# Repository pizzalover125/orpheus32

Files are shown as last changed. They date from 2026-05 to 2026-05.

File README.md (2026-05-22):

# orpheus32



An ESP32 devboard made for Hack Club. A rival to the famous Orpheus Pico. 

### features
- 23 GPIO
- Integrated WiFi + Bluetooth
- 2x UART
- 2x DAC (8-bit)
- SPI, I2C, I2S support
- User-addressable NeoPixel

### schematic + PCB




### KiCAD Render




### BOM
- PCB: $40.30 (incl. JLCPCB PCB, Assembly, Shipping, Customs, Taxes)
- Detailed BOM located in BOM.csv

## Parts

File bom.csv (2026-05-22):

Designator | Footprint | Quantity | Value | LCSC Part #
C2, C3, C4, C5, C6 | 0603 | 5 | 100nf
C7 | 0603 | 1 | 22uf
D1 | D_SOD-123 | 1 | B5819W
D2, D3 | 0603 | 2 | LED
D4 | LED_SK6812MINI_PLCC4_3.5x3.5mm_P1.75mm | 1 | SK6812MINI
J1 | USB_C_Receptacle_HRO_TYPE-C-31-M-12 | 1 | USB_C_Receptacle_USB2.0_16P
J2, J3 | PinHeader_1x15_P2.54mm_Vertical | 2 | Conn_01x15_Pin
Q1, Q2 | SOT-23 | 2 | SS8050
R1, R2 | 0603 | 2 | 5.1k
R3 | 0603 | 1 | 1K
R4, R5, R6 | 0603 | 3 | 10K
R7 | 0603 | 1 | 220R
SW1, SW2 | SW_Push_SPST_NO_Alps_SKRK | 2 | SW_Push
U1 | ESP32-WROOM-32 | 1 | ESP32-WROOM-32
U2 | SOIC-16_3.9x9.9mm_P1.27mm | 1 | CH340C
U3 | SOT-223-3_TabPin2 | 1 | AMS1117-3.3

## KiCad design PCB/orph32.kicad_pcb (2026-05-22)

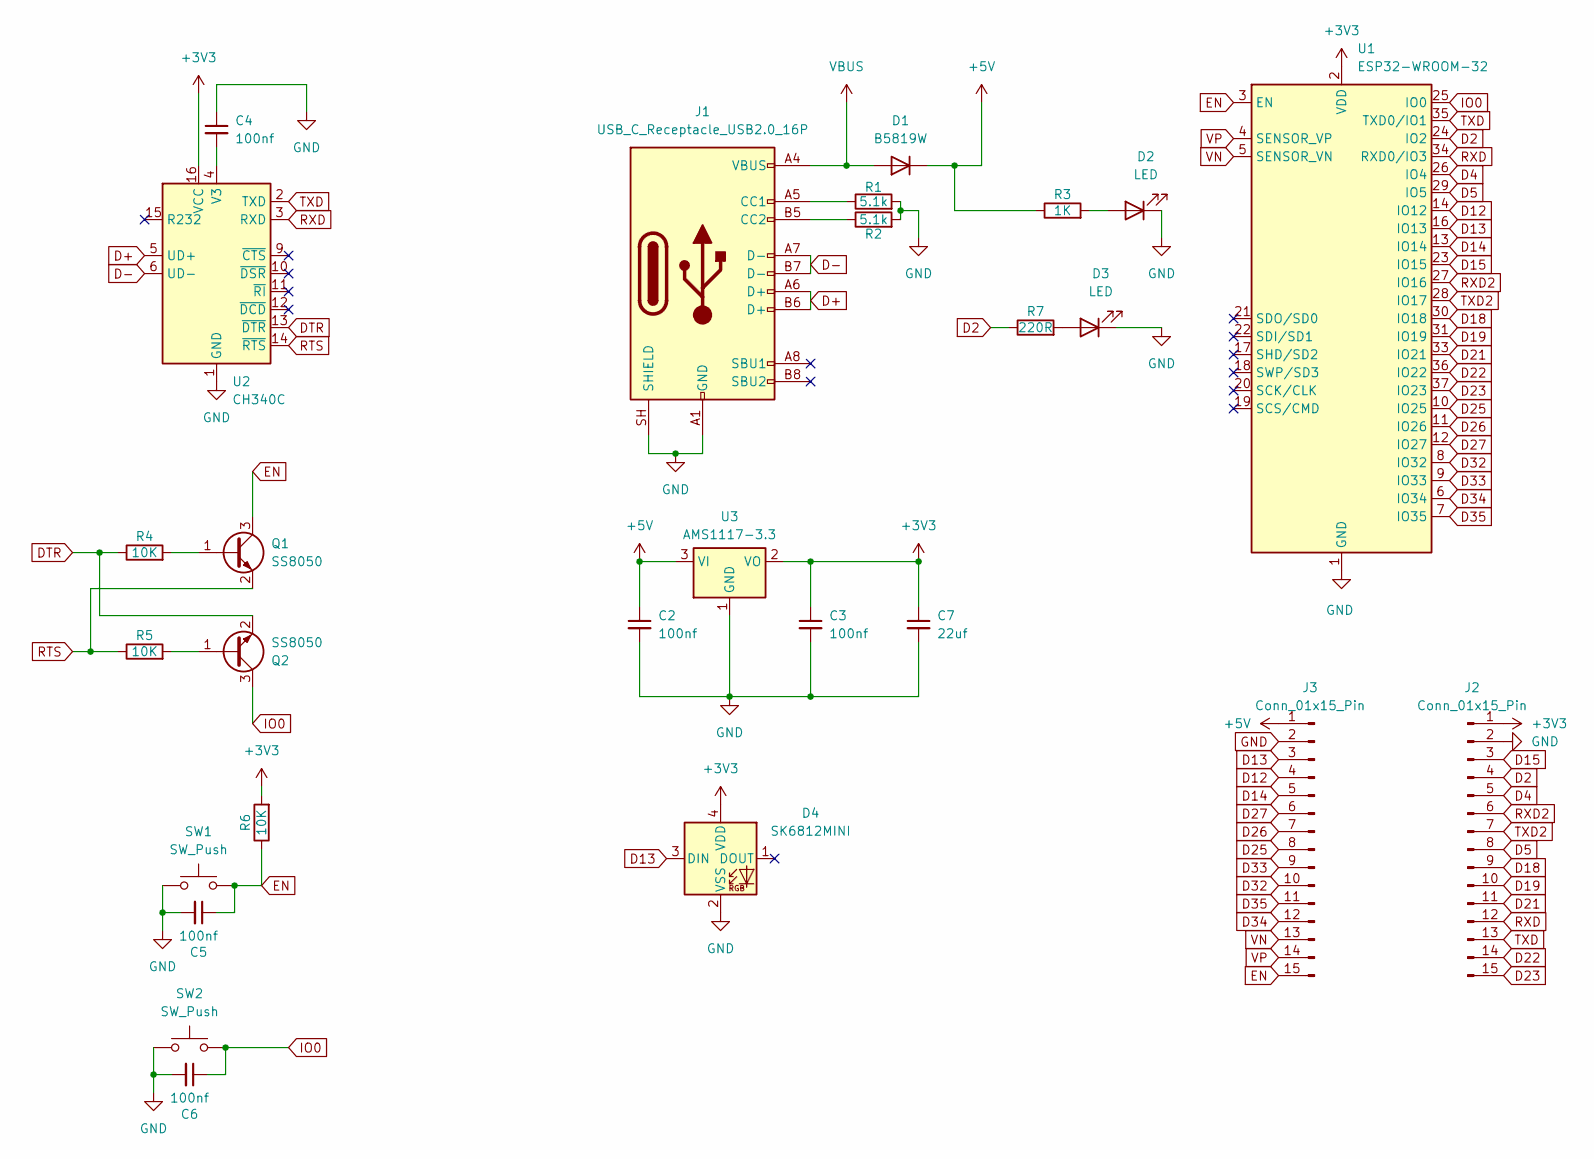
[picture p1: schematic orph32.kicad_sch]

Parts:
C2, C3, C4, C5, C6: 100nf; C_0603_1608Metric
C7: 22uf; C_0603_1608Metric
D1: B5819W; D_SOD-123
D2, D3: LED; LED_0603_1608Metric
D4: SK6812MINI; LED_SK6812MINI_PLCC4_3.5x3.5mm_P1.75mm
J1: USB_C_Receptacle_USB2.0_16P; USB_C_Receptacle_HRO_TYPE-C-31-M-12
J2, J3: Conn_01x15_Pin; PinHeader_1x15_P2.54mm_Vertical
Q1, Q2: SS8050; SOT-23
R1, R2: 5.1k; R_0603_1608Metric
R3: 1K; R_0603_1608Metric
R4, R5, R6: 10K; R_0603_1608Metric
R7: 220R; R_0603_1608Metric
SW1, SW2: SW_Push; SW_Push_SPST_NO_Alps_SKRK
U1: ESP32-WROOM-32
U2: CH340C; SOIC-16_3.9x9.9mm_P1.27mm
U3: AMS1117-3.3; SOT-223-3_TabPin2

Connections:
+3V3: C3.1, C7.1, D4.4 (VDD), J2.1, R6.2, U1.2 (VDD), U2.16 (VCC), U3.2 (VO)
+5V: C2.1, D1.1 (K), J3.1, R3.1, U3.3 (VI)
D2: J2.4, R7.1, U1.24 (IO2)
D4: J2.5, U1.26 (IO4)
D5: J2.8, U1.29 (IO5)
D12: J3.4, U1.14 (IO12)
D13: D4.3 (DIN), J3.3, U1.16 (IO13)
D14: J3.5, U1.13 (IO14)
D15: J2.3, U1.23 (IO15)
D18: J2.9, U1.30 (IO18)
D19: J2.10, U1.31 (IO19)
D21: J2.11, U1.33 (IO21)
D22: J2.14, U1.36 (IO22)
D23: J2.15, U1.37 (IO23)
D25: J3.8, U1.10 (IO25)
D26: J3.7, U1.11 (IO26)
D27: J3.6, U1.12 (IO27)
D32: J3.10, U1.8 (IO32)
D33: J3.9, U1.9 (IO33)
D34: J3.12, U1.6 (IO34)
D35: J3.11, U1.7 (IO35)
D+: J1.A6 (D+), J1.B6 (D+), U2.5 (UD+)
D-: J1.A7 (D-), J1.B7 (D-), U2.6 (UD-)
DTR: Q2.2 (E), R4.1, U2.13 (~DTR)
EN: C5.1, J3.15, Q1.3 (C), R6.1, SW1.2, U1.3 (EN)
GND: C2.2, C3.2, C4.1, C5.2, C6.2, C7.2, D2.1 (K), D3.1 (K), D4.2 (VSS), J1.A1 (GND), J1.A12 (GND), J1.B1 (GND), J1.B12 (GND), J1.SH (SHIELD), J2.2, J3.2, R1.2, R2.2, SW1.1, SW2.1, U1.1 (GND), U1.15 (GND), U1.38 (GND), U1.39 (GND), U2.1 (GND), U3.1 (GND)
IO0: C6.1, Q2.3 (C), SW2.2, U1.25 (IO0)
unnamed: D2.2 (A), R3.2
unnamed: D3.2 (A), R7.2
unnamed: J1.A5 (CC1), R1.1
unnamed: J1.B5 (CC2), R2.1
unnamed: Q1.1 (B), R4.2
unnamed: Q2.1 (B), R5.2
unnamed: C4.2, U2.4 (V3)
RTS: Q1.2 (E), R5.1, U2.14 (~RTS)
RXD: J2.12, U1.34 (RXD0/IO3), U2.3 (RXD)
RXD2: J2.6, U1.27 (IO16)
TXD: J2.13, U1.35 (TXD0/IO1), U2.2 (TXD)
TXD2: J2.7, U1.28 (IO17)
VBUS: D1.2 (A), J1.A4 (VBUS), J1.A9 (VBUS), J1.B4 (VBUS), J1.B9 (VBUS)
VN: J3.13, U1.5 (SENSOR_VN)
VP: J3.14, U1.4 (SENSOR_VP)

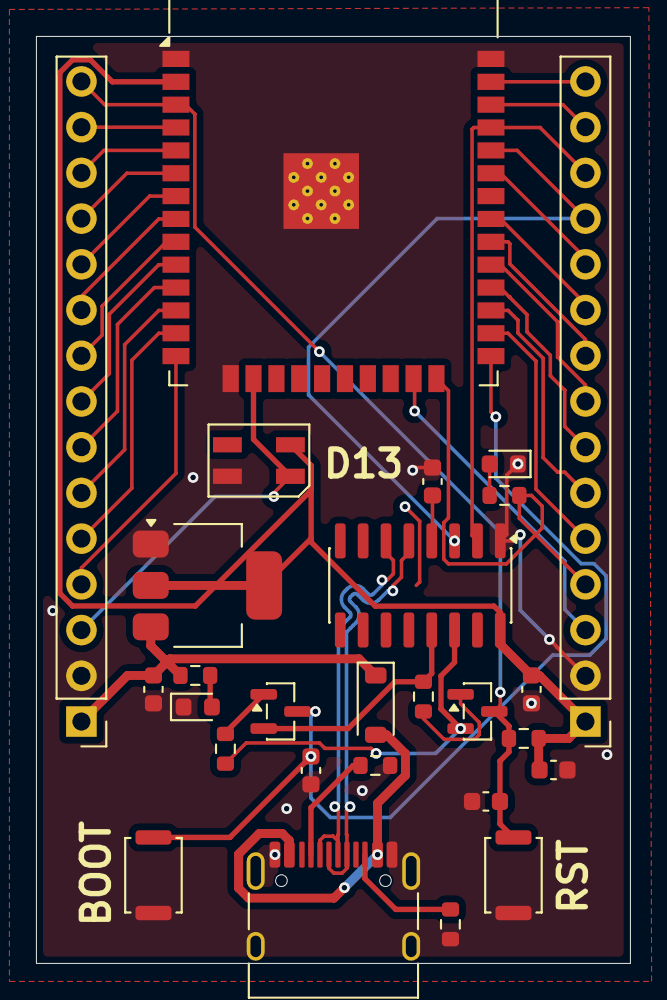
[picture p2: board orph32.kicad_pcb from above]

Board: 2 copper layers, 33.0 x 51.5 mm, 27 parts (0 on the bottom side), 42 nets.

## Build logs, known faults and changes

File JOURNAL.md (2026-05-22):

# journal
Total Time Spent: 13 hrs

### 5/18: rev 1 (3hrs)
- During highway, Jenin had this idea to make an ESP32 devboard called Orpheus32, but ended up never making it and granted me permission to make it
- I never made it... until now!
- im going to use KiCad
- going to use WROOM-32
- realized that it doesn't have easy USB pins like RP2040; need a USB to UART coverter
- after some vary minimal research, it looks like CH340C is the standard for the converter
- using LDO AMS117 3.3v edition
- working on USB-C
- need B5819W diode
- adding power LED
- following standard conventions for the first time by having GND face down and VCC/VBUS/+5V/etc face up



- USBC done



- LDO done



- USB to UART done



- buttons done



- actual ESP32 + pins done also!



- ok assigned footprints
- will start PCB now... wow this project is super easy thus far



- got general layout sort of... need to add components



- components added
- time to route
- ill use differential pair
- surprisingly not too difficult
- bruh i messed up schematic
- ok i added ground planes and am done with rev1!
- ill get a 3d model of the USBC first



- ok time to find bugs and do more revisions!

### 5/18: rev 2 (2hrs)
- time to fix everything I did wrong, such as:



- also apparently my routing is inefficient

- REROUTED EVERYTHING AGAIN BUT IT STILL DIDN"T WORK
- AHHHHH



- time to watch https://www.youtube.com/watch?v=KgOQaBUPiBo
- ok that vid no good lets try https://www.youtube.com/watch?v=v2okbB05piE
- AI slop vid; nvm lets try https://www.youtube.com/watch?v=0tuuMSxcVxg
- got it working!



- w render
- and we are done with routing for rev2... wow this is turning out great! next rev, need to minimize vias from 15 to like 5



### 5/19: rev 3 (3hr)
- @Rudy on Slack told me to use a ESP32 with built-in UART-to-USB
- ig thats what we are doing for this
- after brief research, I found ESP32-S3-WROOM-1 with 36 GPIO
- will read https://documentation.espressif.com/esp32-s3-wroom-1_wroom-1u_datasheet_en.pdf
- idk if I even should create a board bc its going to be super basic
- copied USB-C w/o diode
- going to use same power circuitry
- added buttons



- bruh my schematic feels so basic



- pcb also feels too basic... idk if this is worth it cause its too basic

- ok im back after a couple of hours
- i'm going to make this a sensor board
- finally mastered differential pairs in KiCad w https://www.youtube.com/watch?v=M13QxtPVrXY!
- wait routing this is impossible



- waiting for expert resposne in Slack; going to select some chips to use
- after brief research, i've decided to use BME280 and LSM6DS3
- BME280 is temperature, while the LSM6DS3 is accelorometer



- after much reading of datasheets, came up with this! hopefully it is correct



- rev 3 is complete!

### 5/20: rev 3.1 (2hr)
- I fixed DRC errors that Taran pointed out
- now i want to add a neopixel to make it look cooler
- going to use SK6812 cause why not
- routed it!
- will add 3d model
- ok added it from SnapEDA
- wait the headers are reversed; need to fix



- time for silkscreen
- raygen wants me to add another neopixel
- was not planning to, but sure
- added!



 - going to view other devboards
 - notes from other breadboards:
   - label schematic to make it pretty
   - label pins (seems to be very important)
   - hack club logo + other silkscreen art
- ok im locked in now
- wow this is harder than I expected
- first half done! one more half to go
- had a bunch of problems choosing font and positioning properly



- made post on Hack Club Slack
- ok i think thats it for now; will come back to fix  problems, tidy schematic, and prepare to submit!
- seems like no major errors as nobody has said much on Slack
- Taran told me to add which GPIO are being used for sensors, so I did that!
- going to create order on JLC and source parts!



- im doing everything except the pins cause i don't really need them PCBA



- ok i can do a lot of optimization
- but first, i need to fix all the things Rudy mentioned
- ahhh too tired for this; will do tmrw ig

### 5/21: rev 3.2 + rev4 (3hr)
- redoing all the passives
- going to change placement as well



- some changes to values + decoupling caps added
- done with pairs + placement!





- wowoowowowow
- time to see price bc i lessened number of items
- bruh price is $93 now
- $180 w customs and shipping 😢
- I HAVE TO RESTART bc ESP32-S3 is too expensive
- luckily i have rev2 still available which uses



- routing time
- wait ill add SK6218-mini
- ok added



- PCB done! need to add silkscreen now!



- both sides done!
- time to add Hack Club logo



- BOOM!
- ok sent message in slack
- idk i feel like accelorometer is not needed
- i think i might prepare for submission now
- ok going to prepare for submission
- added cool labels to evrything
- creating render cause why not

- Render




- PCB + Schematic




- KiCAD Render




- JLC comes out to $40.30 👀
- ok time to upload files and prepare README

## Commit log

2026-05-20 Revise JOURNAL.md with updates on rev 3
    Updated the time spent on rev 3 and added additional notes on sensor board development.
2026-05-21 Revise JOURNAL.md with new PCB design updates
    Updated revision details and added new entries for PCB design progress.
2026-05-22 added everything
    [bom.csv, designators.csv, orph32.kicad_pcb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]
